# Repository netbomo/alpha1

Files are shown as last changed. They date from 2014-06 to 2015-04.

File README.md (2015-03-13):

alpha1
======

Prototype de shield pour arduino, permettant de monitorer une éolienne.

Voir les premières données :

http://desplanchesdepalette.org/colibri/Colibri_Energie.html

Projet :
--------

Le but est de créer une shield pouvant par exemple créer un node pour le système OpenEnergyMonitor ou se greffant sur une carte Akeru, une carte Arduino Yun...

###Capteur désirés :

- Anémomètre
- girouette
- capteur de courant
- capteur de tension 

note : Pour l'instant ma carte emontx ne fontionne plus, et la sonde de courant CT ne donne plus de valeur correcte, donc nous utilisons un WattNode Pulse ainsi qu'une carte arduino UNO.

###Etat des lieux :
 Le systême fonctionne à l'atelier, mais pose problème en situation, la présence proche du réseau à l'air d'en être la cause. La prochaine modification sera de mettre le systême dans un boitier métalique avec une mise à la masse. Une carte de meilleure qualité devrait aider aussi.

Le premier prototype est installé avec la version du programme netbomo.ino

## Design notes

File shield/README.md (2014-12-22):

Caractéristiques recherchées pour le shield :
=============================================

- connectique pour la carte arduino UNO
- 2 interfaces anémomètres
- 1 interface girouette
- 1 capteur de tension comme sur le système Open Energy Monitor
- 1 CT (mesures de courant) comme sur le système Open Energy Monitor

Avoir la possibilité de mettre un modem rfm12b pour être utilisée dans le cadre du projet Open Energy Monitor

Shield caracteristics : 
=======================

- Arduino connectics
- 2 anemometer inputs
- 1 wind vane input
- 1 Voltage sensor
- 1 current sensor
- RFM12B connectics

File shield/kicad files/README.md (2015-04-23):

## Lots of bugs on this card, please don't use it!

### Netbomo schematic :
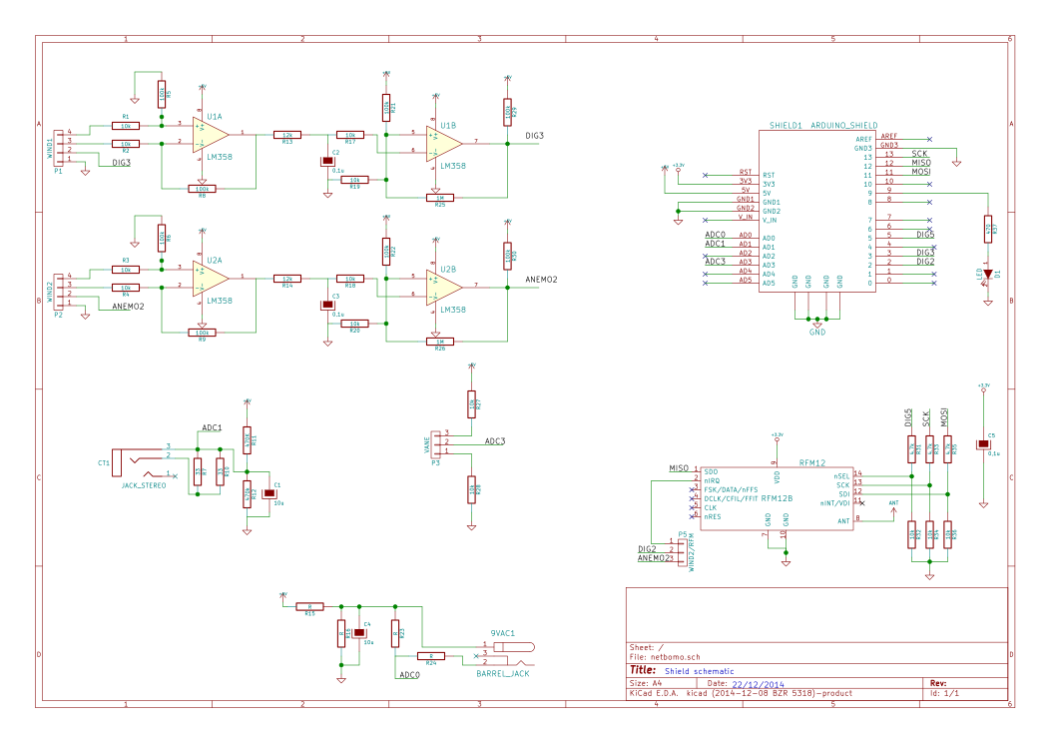
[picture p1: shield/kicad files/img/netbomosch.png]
Netbomo schematic


The "WIND1" and the "WIND2" are composed of 2 op-amp circuits :
  - the first one amplifies "sinusoidal" data coming from the NRG-type anemometers
  - the second one convert it to a square wave curve that can be used afterward to count RPMs

### Netbomo board :
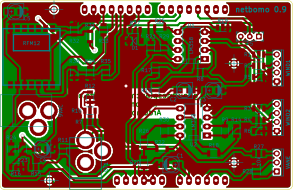
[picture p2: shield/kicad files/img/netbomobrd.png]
Netbomo board


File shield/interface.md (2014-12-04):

Capteur et interface
====================

Nous avons 4 mesures à faire :

- La mesure de la vitesse du vent
- La direction du vent
- La courant électrique fournie par l’éolienne 
- La tension fournie électrique fournie par l'éolienne

### Mesure de la vitesse du vent

Pour mesure la vitesse du vent nous utilisons un anémomètre NGR 40C. Cet anémomètre à l'avantage d'avoir une longue durée de vie (15ans environ). En sortie de l’anémomètre on observe un signal sinusoïdal de fréquence variant entre 0 et 120 Hz et d'amplitude de 40mV à 6V. La vitesse du vent est donnée par la relation [m/s = (Hz x 0,765) + 0.35]. Nous avons donc dut créer l'interface permettant de mesurer la fréquence de ce signal :

Le premier étage est un montage Amplificateur différentiel il permet de récupérer le signal de l’anémomètre et de l'amplifier, on à :

	Vo=10*(V1-V2)

Cette amplification nous permet de lire la fréquence même si l'amplitude des signaux d'entrés est faible.

Le deuxième étage R5-C1 joue le rôle d'un filtre passe bas d'ordre 1. Cela vas permettre de limiter le bruit et les interférences. La fréquence de coupure de ce filtre est de 130Hz car dans le cas ou l’anémomètre délivrerait cette fréquence la vitesse du vent serais de 300 km/h...

Le dernier étage est un comparateur à 2 seuils (trigger de Schmitt). Il va permettre de convertir le signal sinusoïdal en un signal carrée de même fréquence.

### mesure de la direction du vent.

On utilise un girouette : cette girouette est un potentiomètre rotatif : NRG #200

On rentre dans une entrée analogique de la carte arduino avec Vs pour lire la direction du vent.
Comme on envoie des données toutes les 10 minutes il faut réaliser plusieurs mesures avec la girouette pour pouvoir les moyenner et avoir un résultat concernant le vent dominant sur ces 10 minutes et s’il est ou non turbulent.

Pour cela :
On crée une boucle nous permettant de réaliser plusieurs mesures avant l'envoi, dans cette boucle on remap les valeurs entre 0 et 360 degrés puis on divise le cercle en secteur et on incrémente le secteur correspondant à la direction du vent pour pouvoir faire la moyenne on calcule la moyenne pondérée des secteurs par le nombre de valeurs observé dans le secteur et l'écart-type.

### Mesure de puissance

On utilise un « Wattnode pulse » qui se branche sur la ligne avec une pince ampèremétrique et une prise de tension en parallèle.
Ce système va calculer la tension, le courant et le déphasage entre les 2 et sortir un signal carré comprit entre 0 et 5V.

La fréquence de ce signal nous permet d'obtenir la puissance avec la formule :

	P=0,75*f*3600

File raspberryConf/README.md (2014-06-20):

NETBOMO
=======

instalation et configuration du raspberry.

###installation de raspbian sur carte sd:

Utilsation des tutoriels :

installation de l'image raspbian sur carte sd :

http://lea-linux.org/documentations/Installation_de_la_carte_SD_du_Raspberry_Pi

premier boot sur le raspberry:

http://lea-linux.org/documentations/Tutoriel_pour_d%C3%A9buter_avec_le_Raspberry_Pi

###connexion 3g :

http://itsacleanmachine.blogspot.fi/2012/11/raspberry-router.html

copier sakis dans /usr/bin
	
	sudo mv sakis3g /usr/bin/sakis3g

créer un deamon pour sakis3g :

	sudo nano /etc/init.d/sakis3g 

et coller le code de sakis3g

trouver ici:

http://www.raspberrypi.org/forums/viewtopic.php?f=31&t=40529

et modifié pour rajouter la fonction restart.

On lui rajoute la posibilité de s'executer :

	sudo chmod +x /etc/init.d/sakis3g

Création des règles udev pour le téléphone :

voir: 60-zte.rules

Placer dans /etc/udev/rules.d/

Script permettant de verifier la connexion 3g à placer dans /usr/bin/3Gtest :
	
	#! /bin/bash
	# /usr/bin/3Gtest

	PATH=/usr/sbin:/usr/bin:/sbin:/bin

	echo "test de connexion 3G"

	./sakis3g status

	if [[ $?=6 ]]		# Valeur de non connexion
	then sudo ./sakis3g start
	else
        	echo "Already connect"
	fi

On fait un lien symbolique dans /etc/cron.hourly/

	cd /etc/cron.hourly
	sudo ln -s /usr/bin/3Gtest 3Gtest

Comme cela il sera executé toute les heures en cas de perte du réseau

un second pour faire le test au démarrage : (je n'ai pas trouvé comment lancer un script au démarrage avec argument genre sakis3g start)

	cd /etc/init.d/
	sudo ln -s /usr/bin/3Gtest 3Gtest
	sudo update-rc.d 3Gtest defaults

###emoncms : 

Tutoriel:
http://openenergymonitor.blogspot.fr/2012/05/installing-emoncms-on-raspberry-pi.html

deamon oemgateway :

il faut copier le répertoire oem_gateway dans /usb/bin puis placer le script oem_gateway.int.dist dans /usr/bin

	sudo mv ~/oem_gateway-master /usr/bin/oemgateway
	sudo oem_gateway.init.dist /etc/init.d/oemgateway

vous devez arriver à un résultat similaire :
	
	/usr/bin/oemgateway/  	#le repertoire
	   	/oemgateway	# le script

voir oemgateway et oemgateway.conf pour les configurations.

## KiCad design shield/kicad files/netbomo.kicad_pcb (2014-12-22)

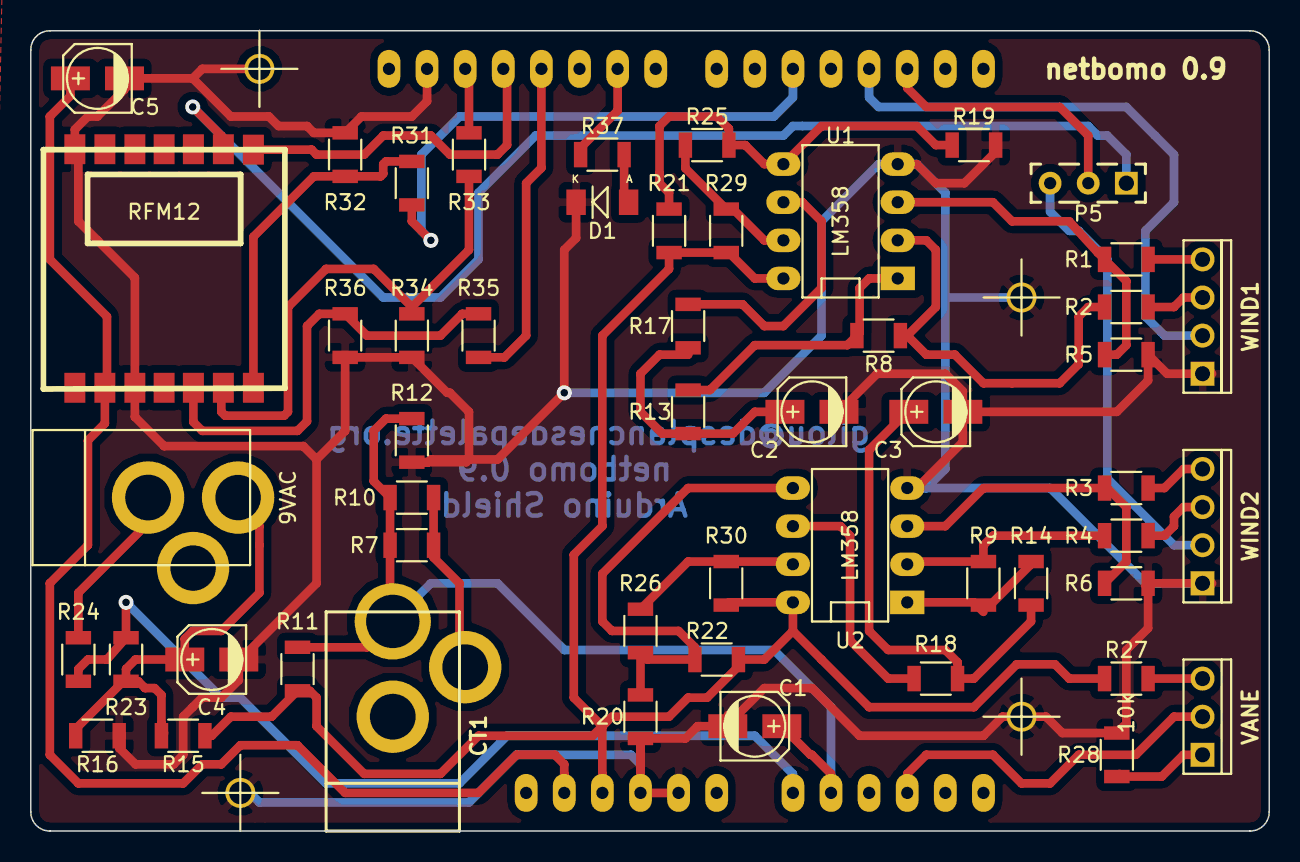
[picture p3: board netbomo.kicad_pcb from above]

Board: 2 copper layers, 82.6 x 53.3 mm, 53 parts (0 on the bottom side), 42 nets.

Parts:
9VAC: BARREL_JACK
C1, C4: 10u; c_elec_4x5.3
C2, C3, C5: 0,1u; c_elec_4x5.3
CT1: JACK_STEREO; JACK_2.1_DC
D1: LED; Diode-MiniMELF_Standard
P1: WIND1; BORNIER_04
P2: WIND2; BORNIER_04
P3: VANE; BORNIER_03
P5: WIND2/RFM; PAD_3
R1, R2, R3, R4, R17, R18, R19, R20, R27, R28, R32, R34, R36: 10k; R_1206
R5, R6, R8, R9, R21, R22, R29, R30: 100k; R_1206
R7, R10: 33; R_1206
R11: 470K; R_1206
R12: 470k; R_1206
R13, R14: 12k; R_1206
R15, R16, R23, R24: R; R_1206
R25, R26: 1M; R_1206
R31, R33, R35: 4.7k; R_1206
R37: 470; R_1206
RFM12: RFM12
U1, U2: LM358; DIP-8__300_ELL
netbomo 0.9: ARDUINO_SHIELD; ARDUINO_SHIELD_2

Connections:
+3.3V: C5.1, RFM12.9, netbomo 0.9.3V3
+5V: R11.1, R15.2, R21.1, R22.1, R27.1, R29.1, R30.1, U1.8, U2.8, netbomo 0.9.5V
/ADC0: R23.2, R24.2, netbomo 0.9.AD0
/ADC1: C1.1, CT1.3, R7.1, R10.1, R11.2, R12.1, netbomo 0.9.AD1
/ADC3: P3.2, netbomo 0.9.AD3
/ANEMO2: P2.2, P5.3
/DIG2: P5.2, netbomo 0.9.2
/DIG3: P1.2, netbomo 0.9.3
/DIG5: R31.1, netbomo 0.9.5
/MISO: RFM12.1, netbomo 0.9.12
/MOSI: R35.1, netbomo 0.9.11
/SCK: R33.1, netbomo 0.9.13
GND: C1.2, C2.2, C3.2, C4.2, C5.2, D1.2, P1.1, P2.1, R5.1, R6.1, R12.2, R16.2, R19.2, R20.2, R28.2, R32.2, R34.2, R36.2, RFM12.7, RFM12.10, U1.4, U2.4, netbomo 0.9.GND1, netbomo 0.9.GND2, netbomo 0.9.GND3
unnamed: 9VAC.1, C4.1, R15.1, R16.1, R23.1
unnamed: 9VAC.2, R24.1
unnamed: C2.1, R13.1, R17.2
unnamed: C3.1, R14.1, R18.2
unnamed: CT1.2, R7.2, R10.2
unnamed: D1.1, R37.2
unnamed: P1.3, R2.2
unnamed: P1.4, R1.2
unnamed: P2.3, R4.2
unnamed: P2.4, R3.2
unnamed: P3.1, R28.1
unnamed: P3.3, R27.2
unnamed: P5.1, RFM12.2
unnamed: R1.1, R5.2, U1.3
unnamed: R2.1, R8.2, U1.2
unnamed: R3.1, R6.2, U2.3
unnamed: R4.1, R9.2, U2.2
unnamed: R8.1, R13.2, U1.1
unnamed: R9.1, R14.2, U2.1
unnamed: R17.1, U1.6
unnamed: R18.1, U2.6
unnamed: R19.1, R21.2, R25.2, U1.5
unnamed: R20.1, R22.2, R26.2, U2.5
unnamed: R25.1, R29.2, U1.7
unnamed: R26.1, R30.2, U2.7
unnamed: R31.2, R32.1, RFM12.14
unnamed: R33.2, R34.1, RFM12.13
unnamed: R35.2, R36.1, RFM12.12
unnamed: R37.1, netbomo 0.9.9

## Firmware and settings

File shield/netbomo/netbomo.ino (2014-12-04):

// Définitions pour l'anémomètre 
float windPower = 0; 
float hertz =0;
int ibiTime_anemo_1 = 0;
int lastTime_anemo_1 = 0;
int temp_errorData =0;

// Définitions pour le wattNode
float powerProductAverage = 0;
int ibiTime_PowerProduct=0;
int lastTime_PowerProduct = 0; 

// Définition pour la girouette
const int WindVane = 0;
int windVaneValue = 0;
int windVaneOffSet = 140;
int columns = 16;
int windDirection = 0;
int windDirectionAverage = 0;

int node_id=6;  // Référence du node pour Emoncms

// déclaration temps d'attente : ici 10 min
unsigned long WaitToSendData = 600000;
unsigned long WaitWindVane = 5000;
unsigned long global_lastTime;
unsigned long time_test=0;

void setup() { 

  Serial.begin(9600); // Initialisation de la liaison serie

  attachInterrupt(1, windSpeed, RISING); 
  attachInterrupt(0, powerProduct, RISING);

  lastTime_anemo_1 = millis(); 
  lastTime_PowerProduct = millis();
  global_lastTime = 0;

}


void loop(){

  time_test = millis()-global_lastTime; // référence flotante de temps

  if (time_test/WaitWindVane>=1) {
    windVaneDir();
  }

  if (time_test/WaitToSendData>=1){

    noInterrupts();

    sendData();

    interrupts();
    global_lastTime=millis(); 
  }
} 

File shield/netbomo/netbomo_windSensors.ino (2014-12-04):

// Gestion capteurs

void windSpeed() {//interruption pour comptage des impulsions pour l'anémomètre
  /* Calculer la direction du vent entre deux fronts montant*/

  ibiTime_anemo_1 = millis(); // On ancre le temps
  
  if (ibiTime_anemo_1-lastTime_anemo_1>20&&ibiTime_anemo_1-temp_errorData>25){
    hertz = (float)1000/(ibiTime_anemo_1-lastTime_anemo_1);
    windPower = (windPower + hertz*0.765+0.35)/2;
    if (windPower==0.35) windPower=0.0;
    temp_errorData=lastTime_anemo_1;
    lastTime_anemo_1 = ibiTime_anemo_1;
    }else if (ibiTime_anemo_1-temp_errorData<=25){
      temp_errorData=ibiTime_anemo_1;
    }
  }

void powerProduct(){
  ibiTime_PowerProduct=millis();
  powerProductAverage= (powerProductAverage + (0.750*1000/(ibiTime_PowerProduct-lastTime_PowerProduct)*3600))/2;
  lastTime_PowerProduct = ibiTime_PowerProduct;
}


void windVaneDir(){
  windVaneValue = map(analogRead(WindVane), 0, 1023, 0, 359);
  if (windVaneValue<windVaneOffSet) windVaneValue = 360 - windVaneOffSet + windVaneValue;
  else windVaneValue = windVaneValue - windVaneOffSet;
  windDirection = (windVaneValue + (360/(2*columns)))/(360/columns);
  if (windDirection == columns) windDirection = 0;
  windDirectionAverage = (windDirectionAverage + windDirection)/2;
}

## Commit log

2014-06-20 add Raspberry conf
2014-06-20 edit raspberryConf/README.md
2014-06-24 add schematic
    [schematic.sch]
2014-08-08 The windWane representation has been modified
    [perturbations.ods]
2014-12-04 clean in repositories
    [netbomo.kicad_pcb, netbomo.sch, schematic.brd]
2014-12-16 update kicad files
    [netbomo.kicad_pcb, netbomo.sch]
